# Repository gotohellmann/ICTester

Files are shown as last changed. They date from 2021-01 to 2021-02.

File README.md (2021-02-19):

# ICTester

IC Tester for the classic CMOS and TLL ICs with Touch Display

**Beware 5V ICs only!**

GPL v3 License - Open Hard- and Software

Code by  **Frank Hellmann**, 2019
http://www.gotohellmann.com/

based on **Akshay Bawejas** code
http://www.akshaybaweja.com/
https://github.com/akshaybaweja/Smart-IC-Tester

If you like it please leave a ⭐!

For hardware requirements and libraries used see below

### Versions:

**Version 2.6**
----------------------------------------------
- update: updated chipdb.txt with 150+ new ICs
          and checked in new test vectors
- new:    version string for chipdb.txt
- new:    Z tag in chipdb.txt for high-Z check
          needs PCB rework for 1M pull-downs,
          checks not implemented in Version 2.6
- new:    NOVECTORS tag for ICs without tests
          this will only display the IC in manual
- bugfix: Auto: sometimes displays wrong IC pinout    
- update: new CLK code for multiple clockpins
          (thanks, @Hans Hübner)
- new:    Auto: flip result pages back and fore

**Version 2.5**
----------------------------------------------
- new:    added LED support to code
- bugfix: pin order corrected for 20pin ICs
- update: updated chipdb.txt with new ICs
- overall "refactoring" of code ;)

 ### Platform & Hardware needed:
 
- This project needs the [Arduino IDE 1.8.10+](https://www.arduino.cc/en/software)
- a **Arduino Mega 2560** Module
- an **ILI9341** 240x320 Pixel RGB TFT LCD Touch Display Shield
- a 4GB Micro-SD Card that fits the Display Shield 
- the IC Tester PCB with:
   - a 20pin ZIF Socket
   - single row pinheaders (1x6pin, 1x8pin, and two 2x18pin)
   - optional Red/Green-LED (Common Cathode) plus two 220Ohm resistors
   - optional White LED plus one 220Ohm resistors and some heatshrink tubing

### Populating the PCB

- Place the PCB with the soldermask upwards and the ZIF socket left hand side
- First solder the ZIF socket with the lever downwards, as the silkscreen shows
- Optional Good/Fail LED:
    - Solder the Red/Green LED with the Red LED towards the left side
    - Solder in the two 220Ohm resistors R2 and R3
- Optional Worklight LED:
    - Solder in the 220Ohm resistor R1 
    - Keep the long legs of the LED and use some heatshrink to avoid shorts
    - Solder the white LED in and position it
- Solder in the pinheaders
- Plug TFT and PCB into the Arduino Mega 2560

### Setting Up and Programming

- Format the SDCard as FAT/FAT32 Filesystem
- Copy the database (data/chipdb.txt) into the root folder of the SDCard (chipdb.txt)
- Plug the SDCard into the TFT shield and connect the Arduino Mega to the computer  
- Start the Arduino IDE
- Check you have the following librarys installed (Tools -> Library Manager):
  - **MCUFRIEND_kbv**  (try the **Adafruit_ILI9341** if the display doesn't work)
  - **Adafruit GFX Library**  (included the Bus Library as well)
  - **Adafruit Touchscreen**
- Install the _patched_ SD library from this repository (Sketch -> Library -> .ZIP )
  - **SD_patched** (download from above, includes Arduino Mega Software SPI fix)
- Open the **IC_Tester_v2.6.ino** 
- Select the proper **Arduino Mega 2560** under Tools -> Board -> Arduino AVR Boards
- Select the correct COM port for upload
- Compile and Upload the sketch

### Usage

  **Beware: This Tester is for testing 5V ICs only!**

- Start the IC Tester and marvel at the startup screen 😏 
- Touch to enter main screen
- Make sure the ZIF socket lever is up
- Insert IC as shown on the screen with the notch facing up and pull the lever down

**There are two modes of operation:**
- **Auto** tries to detect what kind of IC is inserted. This is helpful if you have no
  markings on the IC. To use it you'll have to adjust the number of pins of the IC
  with the **Pins** Button and then hit **Auto**. The IC Tester will match it against
  the known ICs and give you the results. You can press the touch screen to go through
  each found match.

- **Manual** will check an inserted IC against the tests stored in the database.
  Hit **Manual** and insert the plain IC number without the family code here
  (an 74HC06 should be entered as *7406*) and hit **OK**. This will run the test and
  display the results. You can savely change the IC and retest again, if you have a
  few of the same type to test.
  
  The manual mode can also be used to get the pinout of an IC. Just leave the socket empty.

### Troubleshooting

- Display doesn't work:
  Most of the TFT Touch Display shields work with parallel inputs, that's the reason to use
  the MCUFRIEND_kbv library. If your display does not work, using the original Adafruit_ILI9341
  library could help.

- SD Card Error:
  The chipdb.txt couldn't be read. Either the file is corrupt (copy it again),  the card formated
  with the wrong filesystem (format it with FAT), the card to big (best 4GB or below) or an older SPI 
  library interfers with the the TFT Touch Display shield. If this is the case, install the SD_patched Library
  from this repository above.

### Help needed!

- I do not have all possible TTL 74** or CMOS 4*** ICs here for testing. So if you'll find one, that shows up
  as "*** not found" consider sending it in or add it to the chipdb.txt and test it. The format is pretty
  straight forward.

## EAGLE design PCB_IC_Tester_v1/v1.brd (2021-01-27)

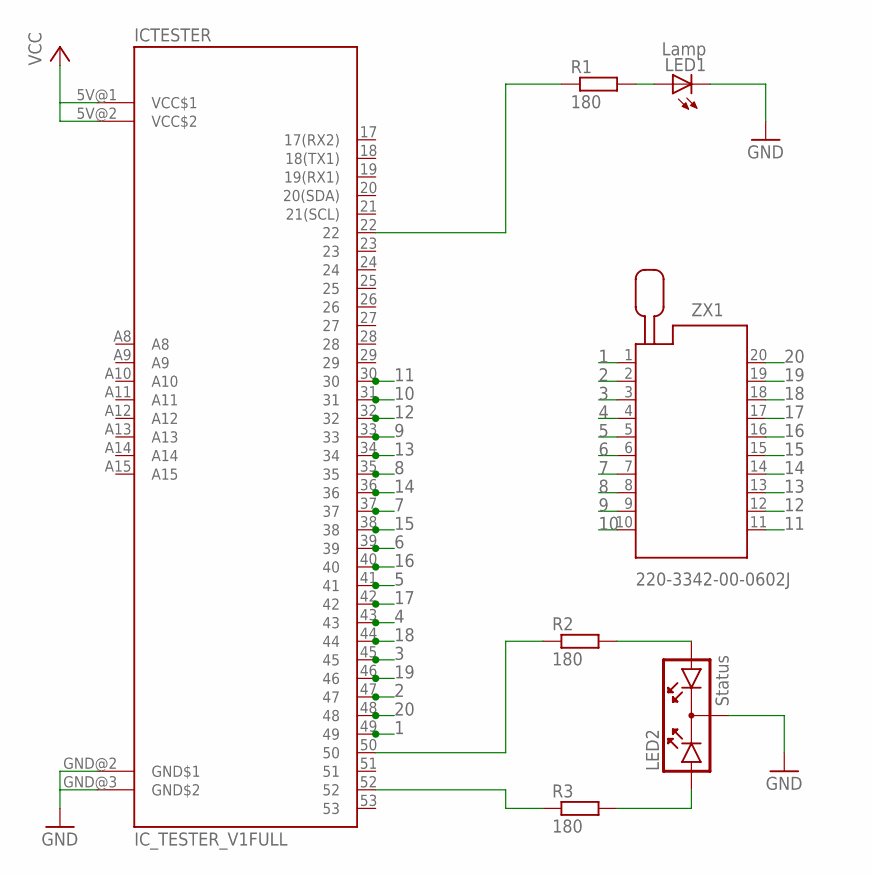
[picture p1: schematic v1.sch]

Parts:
ICTESTER: IC_TESTER_V1FULL; SPARKFUN-BOARDS_ARDUINO_MEGA
LED1: Lamp; LED3MM
LED2: Status; DUOLED
R1, R2, R3: 180; 0204V
ZX1: 220-3342-00-0602J

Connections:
1: ICTESTER.49, ZX1.1
2: ICTESTER.47, ZX1.2
3: ICTESTER.45, ZX1.3
4: ICTESTER.43, ZX1.4
5: ICTESTER.41, ZX1.5
6: ICTESTER.39, ZX1.6
7: ICTESTER.37, ZX1.7
8: ICTESTER.35, ZX1.8
9: ICTESTER.33, ZX1.9
10: ICTESTER.31, ZX1.10
11: ICTESTER.30, ZX1.11
12: ICTESTER.32, ZX1.12
13: ICTESTER.34, ZX1.13
14: ICTESTER.36, ZX1.14
15: ICTESTER.38, ZX1.15
16: ICTESTER.40, ZX1.16
17: ICTESTER.42, ZX1.17
18: ICTESTER.44, ZX1.18
19: ICTESTER.46, ZX1.19
20: ICTESTER.48, ZX1.20
GND: ICTESTER.GND@2 (GND$1), ICTESTER.GND@3 (GND$2), LED1.K (C), LED2.K
unnamed: LED1.A, R1.2
unnamed: LED2.A2, R2.2
unnamed: LED2.A1, R3.2
unnamed: ICTESTER.50, R2.1
unnamed: ICTESTER.52, R3.1
unnamed: ICTESTER.22, R1.1
VCC: ICTESTER.5V@1 (VCC$1), ICTESTER.5V@2 (VCC$2)

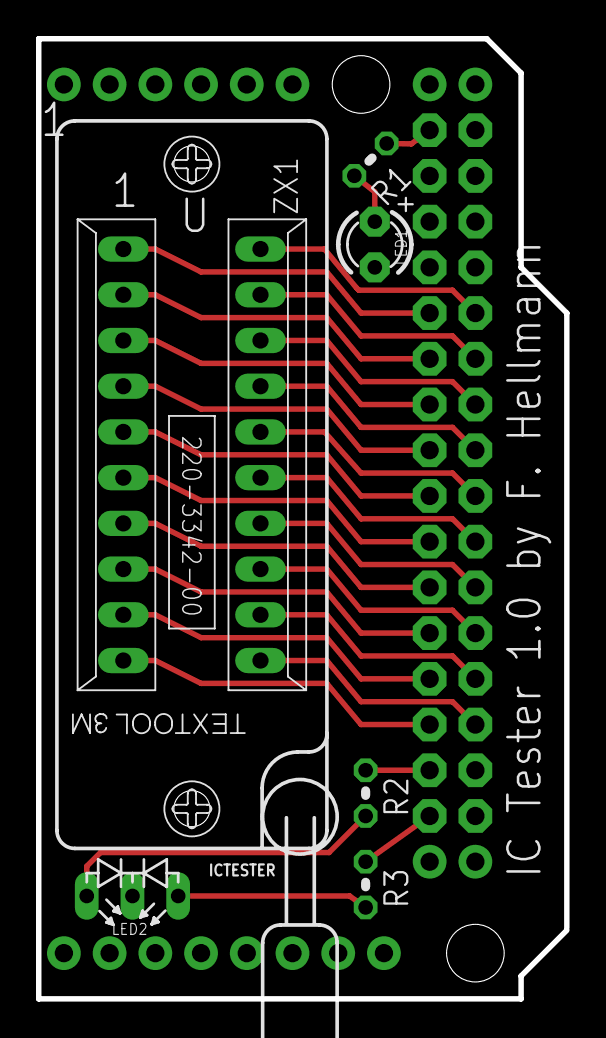
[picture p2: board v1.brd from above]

Board: 2 copper layers, 29.3 x 53.3 mm, 7 parts (0 on the bottom side), 28 nets.

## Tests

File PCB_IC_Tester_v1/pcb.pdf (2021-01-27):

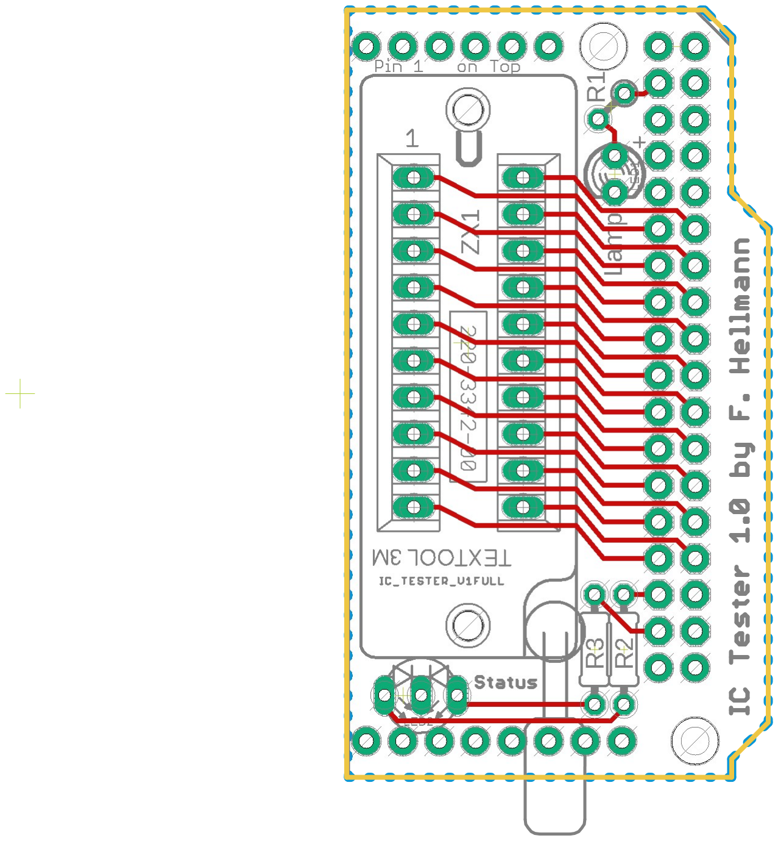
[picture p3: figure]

19.10.2019 23:05 C:\Projects\Eagle\IC Tester\ICTester_v1.brd

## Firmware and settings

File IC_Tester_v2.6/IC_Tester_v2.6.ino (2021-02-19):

// IC Tester for the classic CMOS and TTL ICs
// Beware 5V ICs only!
//
// GPL v3 License - Open Hard- and Software
// 
// by Frank Hellmann, 2019, 2020, 2021
// http://www.gotohellmann.com/
// https://github.com/gotohellmann/ICTester
// 
// based on Akshay Baweja code
// http://www.akshaybaweja.com/
// https://github.com/akshaybaweja/Smart-IC-Tester
//
// The code is based on Arduino.  An Arduino Mega is required.
// For full requirements and installation notes please see: 
// https://github.com/gotohellmann/ICTester
//

#define VERSION "Version 2.6"
//
// ----------------------------------------------
// - update: updated chipdb.txt with 150+ new ICs
//           and checked in new test vectors
// - new:    version string for chipdb.txt
// - new:    Z tag in chipdb.txt for high-Z check
//           needs PCB rework for 1M pull-downs,
//           checks not implemented in Version 2.6
// - new:    NOVECTORS tag for ICs without tests
//           this will only display the IC in manual
// - bugfix: Auto: sometimes displays wrong IC pinout    
// - update: new CLK code for multiple clockpins
//           (thanks, @Hans Huebner)
// - new:    Auto: flip result pages back and fore
//


// REMINDER: 
//-----------
// The SD card library needs patching to work with 
// the TFT LCD on an Arduino Mega! Infos here:
// https://forum.arduino.cc/index.php?topic=487918.0
//
// easiest is to download the patched version from:
// https://github.com/gotohellmann/ICTester/blob/master/SD_patched.zip
// and install in Arduino via Tools -> library manager -> install ZIP 

// Includes from Arduino Library Manager
#include <Adafruit_GFX.h>
#include <MCUFRIEND_kbv.h>
#include <TouchScreen.h>
#define MINPRESSURE 150
#define MAXPRESSURE 1000

// ALL Touch panels and wiring is DIFFERENT
// copy-paste results from TouchScreen_Calibr_native.ino
const int XP = 8, XM = A2, YP = A3, YM = 9; //ID=0x9341
const int TS_MINX = 117, TS_MAXX = 897, TS_MINY = 89, TS_MAXY = 898;
// TS_LR sets the x coordinate for Auto Search result fore and back touch areas
const int TS_LR = 250;

// Assign human-readable names to some common 16-bit color values:
#define BLACK   0x0000
#define BLUE    0x001F
#define RED     0xF800
#define GREEN   0x07E0
#define CYAN    0x07FF
#define MAGENTA 0xF81F
#define YELLOW  0xFFE0
#define WHITE   0xFFFF
#define GRAY    0x8410
#define TTGREEN 0x03ED
#define DRKBLUE 0x0008

//TFT initialization
MCUFRIEND_kbv tft;
TouchScreen ts = TouchScreen(XP, YP, XM, YM, 300);
Adafruit_GFX_Button buttons[12];

//SD CARD
// MEGA256 needs a patch in the SD library, see:
// https://forum.arduino.cc/index.php?topic=487918.0
//
// easiest is to download the patched version from:
// https://github.com/gotohellmann/ICTester/blob/master/SD_patched.zip
// and install in Arduino via Tools -> library manager -> install ZIP 
//
#define MEGA_SOFT_SPI 1
#define chipSelect 10
#define SOFTWARE_SPI 1
#include <SPI.h>
// patched SD library, see above
#include <SD_patched.h>

//Database File name on SD Card
#define fname "chipdb.txt"

//Pin Definitions
const int ledr = 50;
const int ledg = 52;
const int ledw = 22;
const int pin14[] = {30, 32, 34, 36, 38, 40, 42, 43, 41, 39, 37, 35, 33, 31};
const int pin16[] = {30, 32, 34, 36, 38, 40, 42, 44, 45, 43, 41, 39, 37, 35, 33, 31};
const int pin18[] = {30, 32, 34, 36, 38, 40, 42, 44, 46, 47, 45, 43, 41, 39, 37, 35, 33, 31};
const int pin20[] = {30, 32, 34, 36, 38, 40, 42, 44, 46, 48, 49, 47, 45, 43, 41, 39, 37, 35, 33, 31};
String pinname[20] = {"    ","    ","    ","    ","    ","    ","    ","    ","    ","    ","    ","    ","    ","    ","    ","    ","    ","    ","    ","    "};
boolean errpin[20] = {false, false, false, false, false, false, false, false, false, false, false, false, false, false, false, false, false, false, false, false };
int pinCount = 14;  // Default number of Pins on IC
int *pin;

//Structure Definiton for IC
typedef struct {
  String num;
  String name;
} IC;

String currentIC="";
int screenStatus = 0, lastStatus = 0;

// Reset Function, resets Arduino
void(* resetFunc) (void) = 0;

// SD Card init
void SD_init()
{
  // Initialize SD Card Hardware
  pinMode(chipSelect, OUTPUT);

  // If we do not find the SD-Card, notify and reset
  if (!SD.begin(chipSelect)) {
    Serial.println("Card failed, or not present.");
    digitalWrite(ledr,HIGH);
    digitalWrite(ledg,LOW);
    tft.setCursor(16, 170);
    tft.setTextColor(RED);  tft.setTextSize(2);
    tft.print("ERROR:");
    tft.setTextColor(MAGENTA);
    tft.println("SD Card Read Error");
    
    getTouch();
    resetFunc();
  }

  // Open ChipDB and show database version
  File dataFile = SD.open(fname);
  dataFile.seek(2);
  String buffer = dataFile.readStringUntil('\n');
  buffer.trim();

  tft.setCursor(48, 190);
  tft.setTextSize(2);
  tft.setTextColor(MAGENTA);
  tft.println(buffer);

  dataFile.close();

  Serial.println("SD card initialized.");
}


void setup() {
  Serial.begin(115200);

  delay( 100 ); // power-up safety delay

  // LED setup
  pinMode(ledr,OUTPUT);
  pinMode(ledg,OUTPUT);
  pinMode(ledw,OUTPUT);

  digitalWrite(ledr, LOW);
  digitalWrite(ledg, LOW);
  digitalWrite(ledw, HIGH);

  // TFT setup
  tft_init();

  // SD Card Setup
  SD_init();

}

void loop() {
  // First we'll check for touch presses
  TSPoint p = ts.getPoint();
  pinMode(XM, OUTPUT);
  pinMode(YP, OUTPUT);

  if (p.z > MINPRESSURE && p.z < MAXPRESSURE)
  {
    // scale from 0->1023 to tft.width
    p.x = map(p.x, TS_MINX, TS_MAXX, tft.height(), 0);
    p.y = map(p.y, TS_MINY, TS_MAXY, 0, tft.width());

    //Swapping for TFT Rotation 3
    p.x = p.x + p.y; p.y = p.x - p.y; p.x = p.x - p.y;

    delay(10);

    // Check if buttons are pressed

    if (screenStatus == 0)            // Startup Screen
      screenStatus = 1;

    else if (screenStatus == 1)       // Main Screen Buttons
    {
      if (buttons[0].contains(p.x, p.y))
      {
        Serial.println("AUTO MODE");
        screenStatus = 2;
      }
      else if (buttons[1].contains(p.x, p.y))
      {
        Serial.println("MANUAL MODE");
        screenStatus = 3;
      }
      else if (buttons[2].contains(p.x, p.y))
      {
        Serial.println("CHANGE PIN COUNT");
        pinCount += 2;
        if (pinCount>20) pinCount=14;
        currentIC="";
        tft.fillRect(0,185,90,60,BLACK);
        drawTop("IC Tester");
        drawIC(pinCount,currentIC);
        drawStatus(String(pinCount)+" Pin",TTGREEN);
        screenStatus = 1;
      }
      else if (currentIC!="")
      {
        if (buttons[3].contains(p.x, p.y))
        {
          Serial.println("RETEST IC");
          screenStatus = 4;
        }
      }
    }
  }
  
  pinMode(XM, OUTPUT);
  digitalWrite(XM, LOW);
  pinMode(YP, OUTPUT);
  digitalWrite(YP, HIGH);

  // Simple state machine to display the different screens
  // 
  if (screenStatus != lastStatus)     // Check if the button presses need screen updates
  {
    switch (screenStatus)
    {
      case 0: startScreen();          // Show Startup Screen
        break;
      case 1: modeScreen();           // Main Screen  
        break;
      case 2: autoSearch(pinCount);   // Auto Screen
        if (currentIC!=""){           // If we selected an IC before show the Retest button 
          buttons[3].initButton(&tft, 45, 215, 80, 50, GRAY, TTGREEN, WHITE, (char *)"Retest", 2);
          buttons[3].drawButton();
        }
        screenStatus=1;               // Go back to Main Screen
        break;
      case 3: currentIC = getIC();    // Manual Screen, first display the IC Number Input Screen 
        for (int i=0;i<20;i++) pinname[i] = "    ";  // Clear pin descriptions
        modeScreen();                 // display the empty Main Screen again
        if (currentIC != "") {        // if we entered a number do a manual test
          manualSearch(currentIC);    
        }
        screenStatus=1;               // Go back to Main Screen
        break;
      case 4:                         // Retest IC
        if (currentIC != "") {        // if we have a valid IC retest it
          manualSearch(currentIC);  
        }
        screenStatus=1;               // Go back to Main Screen
        break;
    }
    lastStatus = screenStatus;
  }
  delay(5);
}

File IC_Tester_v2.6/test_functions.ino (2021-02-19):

/*
 *  test_functions contains all IC related test routines
 *  
 *  author: Frank Hellmann, mail@gotohellmann.com
 *  
 */
boolean testCase(String test, int pins)
{
  // Helper function to perform IC checks
  boolean result = true;
  int clockPins[20];
  int clocks = 0;

  // Load the hardware pin definition into pin
  switch (pins)
  {
    case 14 : pin = pin14;
      break;
    case 16 : pin = pin16;
      break;
    case 18 : pin = pin18;
      break;
    case 20 : pin = pin20;
      break;
  }
  
  Serial.println("SignalIn : " + test);
  Serial.print("Response : ");

  // Setting up Vcc, GND and input pins
  for (int i = 0; i < pins; i++)
  {
    switch (test[i])
    {
      case 'V' : pinMode(pin[i], OUTPUT); digitalWrite(pin[i], HIGH);
        break;
      case 'G' : pinMode(pin[i], OUTPUT); digitalWrite(pin[i], LOW);
        break;
      case 'L' : digitalWrite(pin[i], LOW); pinMode(pin[i], INPUT_PULLUP);
        break;
      case 'H' : digitalWrite(pin[i], LOW); pinMode(pin[i], INPUT_PULLUP);
        break;
      case 'Z' : digitalWrite(pin[i], LOW); pinMode(pin[i], INPUT_PULLUP);
        break;
    }
  }

  delay(5);

  // Setting output signals
  for (int i = 0; i < pins; i++)
  {
    switch (test[i])
    {
      case 'X' :
      case '0' : pinMode(pin[i], OUTPUT); digitalWrite(pin[i], LOW);
        break;
      case '1' : pinMode(pin[i], OUTPUT); digitalWrite(pin[i], HIGH);
        break;
      case 'C' : clockPins[clocks++] = pin[i]; pinMode(pin[i], OUTPUT); digitalWrite(pin[i], LOW);
        break;
    }
  }

  // Setting up clock pins
  if (clocks)
  {
    for (int i = 0; i < clocks; i++) {
      //Clock Trigger
      pinMode(clockPins[i], INPUT_PULLUP);
      delay(10);
      pinMode(clockPins[i], OUTPUT);
      digitalWrite(clockPins[i], LOW);
    }
  }

  delay(5);

  // Reading and testing outputs
  for (int i = 0; i < pins; i++)
  {
    switch (test[i])
    {
      case 'H' : if (!digitalRead(pin[i])) {
          // Not good! Error! 
          result = false;
          Serial.print('L');
          errpin[i]=true;
        }
        else Serial.print(' ');
        break;
      case 'Z' : if (!digitalRead(pin[i])) {
          // Not good! Error!
          // TODO: Pulldown Pullup checks of High-Z outputs 
          result = false;
          Serial.print('L');
          errpin[i]=true;
        }
        else Serial.print(' ');
        break;
      case 'L' : if (digitalRead(pin[i])) {
          // Not good! Error! 
          result = false;
          Serial.print('H');
          errpin[i]=true;
        }
        else Serial.print(' ');
        break;
      default : Serial.print(' ');
    }
  }
  Serial.println(";");
  if (result == false) {
    Serial.println("Case Result : Error detected!");
  } else {
    Serial.println("Case Result : Test OK!");
  }
  return result;
}


void autoSearch(int pins)
{
  // Auto Search Functions. Checks for matching 
  // IC definitions with the right pin count.
  File dataFile = SD.open(fname);

  String newCase;
  IC newIC;
  int ICpins;
  boolean result;
  IC ans[20];
  unsigned long filepos;
  unsigned long anspos[20];

  if (dataFile)
  {
    int count = 0;
    int i;
    for (i=0;i<20;i++) errpin[i] = false;
    i=0;

    drawStatus("Testing",YELLOW);
    digitalWrite(ledr,HIGH);
    digitalWrite(ledg,HIGH);
    
    while (dataFile.available())
    {
      dataFile.readStringUntil('$');
      // Read IC name and description
      newIC.num = dataFile.readStringUntil('\n');
      newIC.name = dataFile.readStringUntil('\n');
      ICpins = dataFile.readStringUntil('\n').toInt();
      filepos=dataFile.position();

      // If the pin count matches do tests
      if (ICpins == pins)
      {
        result = true;
        for (i=0;i<20;i++) errpin[i] = false;
        drawStatus("Testing",TTGREEN);
        Serial.println("Testing Now");

        // read pin function description in
        i=0;
        while (dataFile.peek() != '#' && i<ICpins)
        {
          pinname[i]=dataFile.readStringUntil('\n');
          i++;
        }
        newCase=dataFile.readStringUntil('\n'); // Dummy Read for #

        // read test cases in and test them
        while (dataFile.peek() != '$')
        {
          newCase = dataFile.readStringUntil('\n');
          newCase.trim();
          if (newCase == "NOVECTORS" || testCase(newCase, ICpins) == false)
          {
              result = false;
              break;
          }
        }

        // check for matches and store answers
        if (result == true)
        {
          Serial.println("\nMatch Found !!\n");
          ans[count] = newIC;
          anspos[count++] = filepos;
          Serial.println(newIC.num+"::"+newIC.name+"::"+filepos);
        }

        drawStatus("Testing",YELLOW);
        Serial.println("Test Completed");
      }
    }
    
    // Show Results
    if (count == 0)
    {
      Serial.println("No Match Found");
      for (i=0;i<20;i++) errpin[i] = false;
      digitalWrite(ledg,LOW);
      digitalWrite(ledr,LOW);
      drawTop("IC Tester");
      drawStatus("Testing",BLACK);
      drawStatus("No Match Found",MAGENTA);
    }
    else
    {
      Serial.println("\nCount : " + String(count));
      digitalWrite(ledg,HIGH);
      digitalWrite(ledr,LOW);
      for (i=0;i<20;i++) errpin[i] = false;
      if (count == 1) {
        drawStatus("1 Match Found",GREEN);
      } else {
        drawStatus(String(count) + " Matches Found",GREEN);
      }
      delay(500);
      int maxcount=count;
      // Display all matches
      while (count--)
      {
        Serial.println(String(count) + ". " + ans[count].num + " : " + ans[count].name);
        // read pin function description in
        dataFile.seek(anspos[count]);
        i=0;
        while (dataFile.peek() != '#' && i<pinCount)
        {
          pinname[i]=dataFile.readStringUntil('\n');
          i++;
        }
        currentIC=ans[count].num;
        drawIC(pinCount,ans[count].num);
        drawTop(ans[count].name);
        if (count>0) {
          drawStatus("<--  "+String(maxcount-count)+"/"+String(maxcount)+"  -->",GREEN);
        } else {
          drawStatus("<--  "+String(maxcount-count)+"/"+String(maxcount)+"  END",GREEN);
        }
        if ( getTouchLR() < TS_LR && count < maxcount ){ 
          if (count < maxcount -1) { 
            count=count+2;
          } else {
            count++;
          }
        }
      }
      currentIC=ans[0].num;
      drawTop(ans[0].name);
      drawStatus("",GREEN);
    }
    dataFile.close();
  }
  else
  {
    // Error while reading IC data
    Serial.print("error opening "); Serial.println(fname);
    dataFile.close();

    tft.fillScreen(BLACK);
    digitalWrite(ledr,HIGH);
    digitalWrite(ledg,LOW);
    tft.setCursor(5, 140);
    tft.setTextColor(RED);  tft.setTextSize(2);
    tft.print("ERROR:");
    tft.setTextColor(MAGENTA);
    tft.println("SD CARD");
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

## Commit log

2021-01-27 Initial commit
    Arduino codebase and database commited
2021-01-27 Initial Commit
    Eagle Project and Gerbers
    [ICTester_v1.GBL, ICTester_v1.GBO, ICTester_v1.GBP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]
2021-01-31 Update IC_Tester_v2.5.ino
    include SD_patched.h with Arduino Mega 2560 Software SPI patches
2021-01-31 Patched SD.h Library
    This library contains a patched SD.h library to access SD Cards with Software SPI on an Arduino Mega 2560
